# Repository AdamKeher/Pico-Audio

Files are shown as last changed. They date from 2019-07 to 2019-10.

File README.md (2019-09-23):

# picoAUDIO
The audio solution dedicated to the TinyPICO.

Arduino Support Library: https://github.com/AdamKeher/Pico-Audio-Arduino

3d printable base: https://github.com/AdamKeher/Pico-Audio/tree/master/base
## About
The picoAUDIO is a fully featured audio solution specially made for the TinyPICO ESP32 development board, featuring an I2S Stereo DAC, I2S Mono MEMS Microphone, builtin 3.7W Stereo Amplifier, dedicated Headphone Amplifier, I2C GPIO Extender and built-in MicroSD card reader.

We utilise a low power NXP UDA1334A IC featuring a clear digital 16/20/24 bit, 44.1kHz, stereo audio DAC. Accompanying the DAC is a Knowles SPH0645 I2S digital mono microphone. This miniature low power MEMS microphone provides a low noise, 24 bit, 44.1kHz stream. Complimenting the DAC is the powerful Maxim MAX98306 3.7W stereo class D amplifier with stero speaker terminals and a Texas Instrumets TPA6132A2 stereo headphone amplifier with 3.5mm audio jack.

A simple mounting socket hosts the TinyPICO development board and connects all of these great features together in a seamless and easy to utilise footprint measuring a tiny 33 mm x 57 mm (1.29in x 2.24in). To provide maximum connectivity the board features a built-in MicroSD card reader and GPIO extender to hookup 8 inputs and outputs for all of your button and LED needs.
## PCB Layout
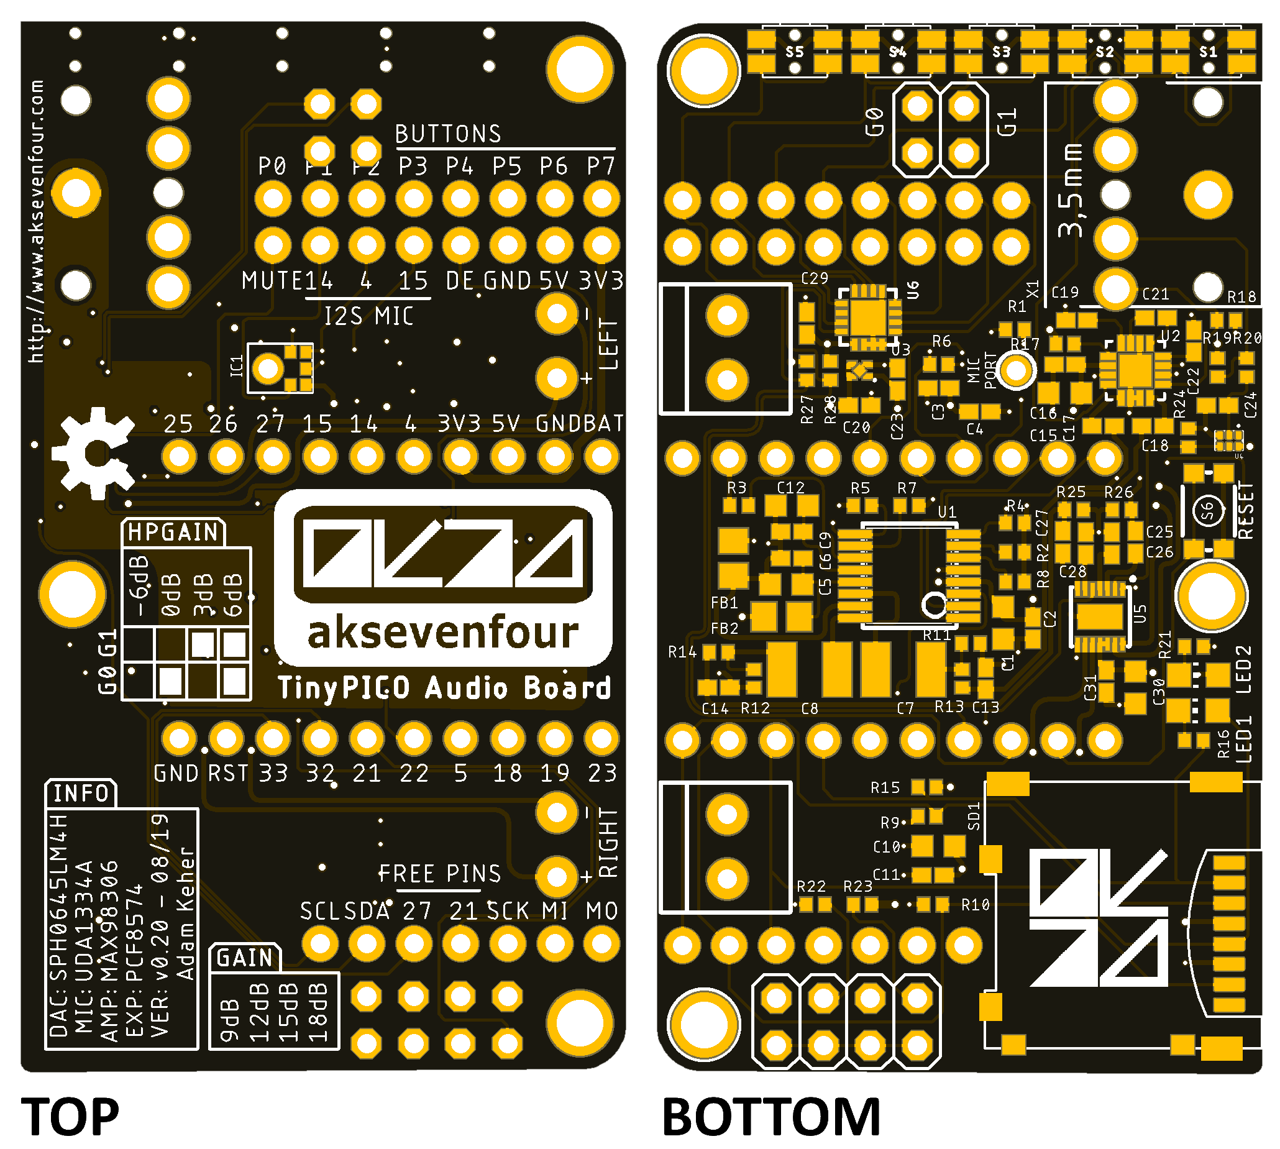
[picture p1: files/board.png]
XCopy Board Image

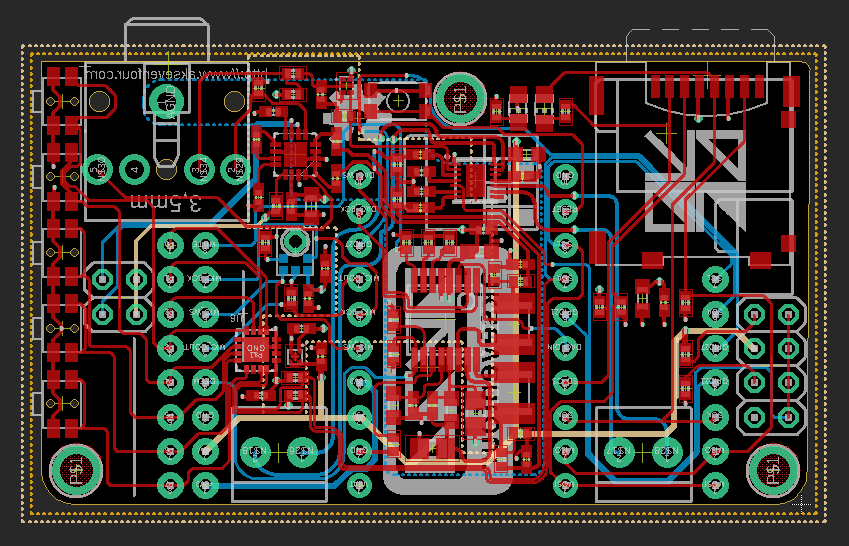
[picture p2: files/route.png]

## Features
The software and hardware used in this project have been made possible by the principle of open hardware and software. Many of the samples have been collected together from a variety of authors and modified to work out of the box with the picoAUDIO for instructional purposes. Please consult each sample project for relevant license and credit.
## Features
* TinyPICO Compatible
  * Simply plug your TinyPICO board into the picoAUDIO and your ready to go
* Audio Out
  * Dedicated Texas Instruments headphone amplifier for distortion free audio.
  * 3.5mm headphone jack. Plug in headphones or line out to an external device.
  * Stereo screw clamp audio terminals. The speaker terminals automatically mute when the 3.5mm jack is used.
* Built-in MicroSD Card
  * Quality Molex mechanism
  * Simple SPI interface
  * Activity LED light
  * Push-Push socket with overhanging edge mounted card for easy insertion
* UDA1334A Stereo DAC
  * Low power audio DAC
  * Integrated digital filter and switchable digital de-emphasis for 44.1 kHz frequency
  * Supports samples from 16 to 100 kHz
  * Simple I2S interface
  * 16/20/24 bit audio
  * High linearity, wide dynamic range and low distortion
* MAX98306 Stereo Amplifier
  * Low power efficient operation
  * 3.7W @ 3Ohm, 10% THD / 1.7W at 8Ohm, 10% THD
  * Spread Spectrum Modulation
  * Five selectable gain levels
  * Excellent click and pop suppression
* TPA6132A2 Headphone Amplifier
  * 25mW Headphone Amplifier for 16/32Ω Headphones with 3.5mm Audio Jack  
  * Unlike most audioboards, the picoAUDIO features a dedicated headphone amplifer
  * Doesn't use caps to drive headphone audio, reducing unwanted noise and distortion
  * Click and pop supression
  * Low power amplifier @ 2.1mA typical supply current
  * Four selectable gain levels
* SPH0645LM4H MEMS Microphone
  * Low power design
  * Simple I2S interface
  * Flat frequency response
  * 24 bit, 44.1kHz audio
  * High SNR of 65dB(A)
  * RF shielded
  * Omnidirectional
* PCF8574 GPIO Extender
  * Low standby current
  * I2C programmable
  * Latched outputs with enough current to drive LEDs
  * 8 Input and Output ports wired to a header with 3 outputs also pre wired to onboard buttons.
## Sample Projects Modified for picoAUDIO
* Stream net radio stations with MP3 support
  * I2C 2x16 character LCD and ILI93411 320x240 TFT display samples provided
* Play audio from SD card with MP3 support
* Record audio to SD card
* Realtime full duplex audio. Vocoder example receives from mic and playback from DAC.

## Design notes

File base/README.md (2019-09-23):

# picoAUDIO
A 3d printable base for the picoAUDIO kindly modelled and provided by Unexpected Maker.

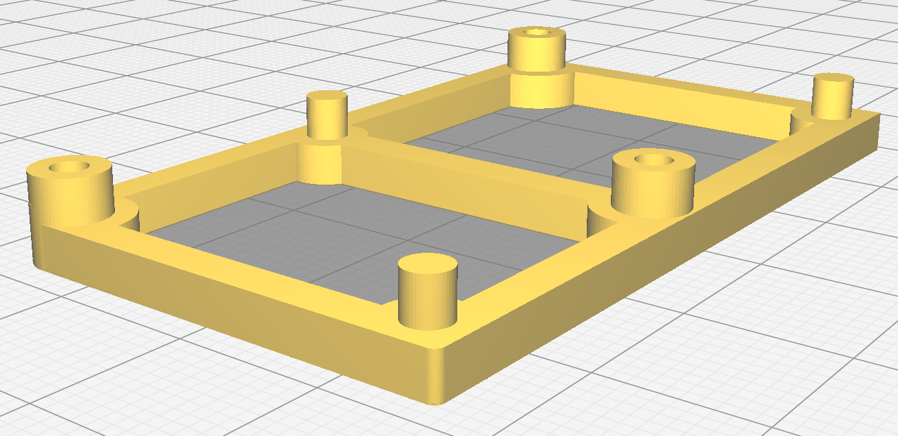
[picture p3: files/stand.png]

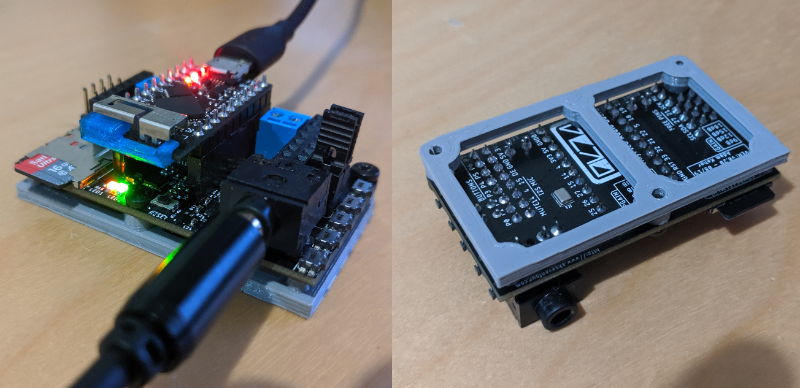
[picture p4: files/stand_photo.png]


https://unexpectedmaker.com/

## Features:
* Raises the picoAUDIO board off the benchtop giving clearance to the pins on the underside of the board.
* Built in standoffs and a flat bottom provide more contact points to the board, increasing stability.
* The bottom of the stand has cut outs to allow the underside pin markings to be visible.
* Does not increase the boards footprint.

## Note
This base requires 2.5mm / M2.5 screws to fix the picoAUDIO to the mounting posts on the base. It is suggested that nylon screws be used to minimise the chance of shorting nearby buttons. If metal screws are used, ensure the head size is small enough to avoid contact with the buttons.

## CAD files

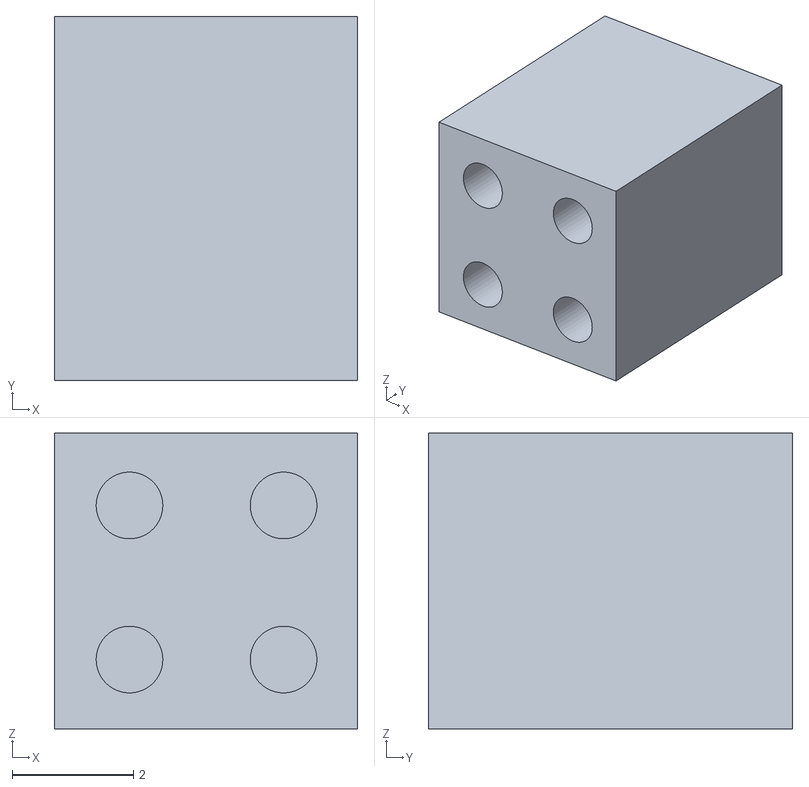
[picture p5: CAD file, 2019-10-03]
base/Headphone Pin Shroud.stl
5.00 x 6.00 x 4.88

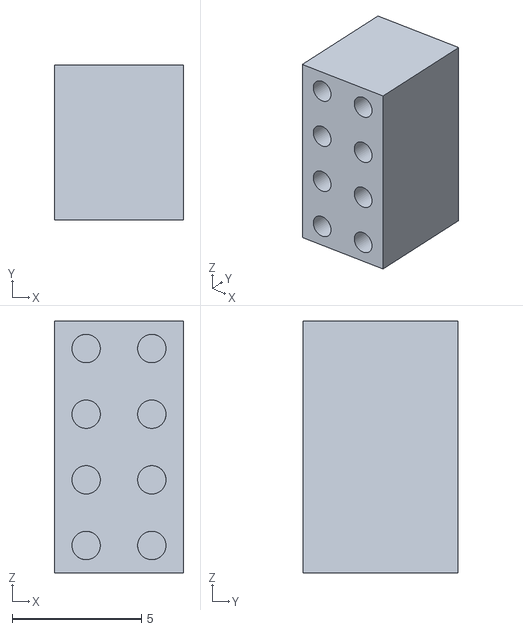
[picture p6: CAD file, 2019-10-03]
base/Speaker Pin Shroud.stl
5.00 x 6.00 x 9.75

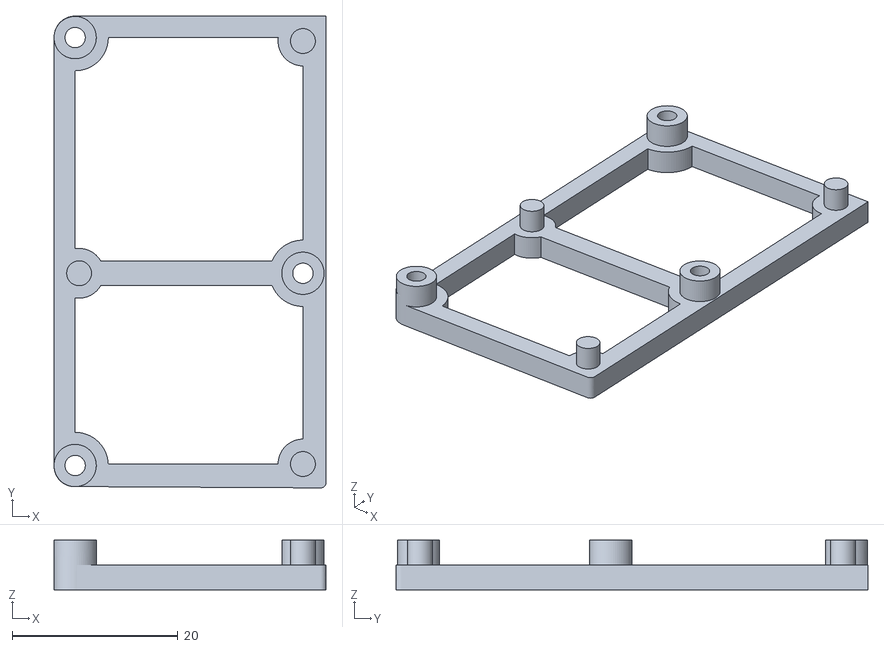
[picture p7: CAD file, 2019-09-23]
base/picoAUDIO base.stl
32.8 x 56.9 x 6.00

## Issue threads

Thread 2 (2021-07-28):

Info silk screen

brad-colbert, 2021-07-28:
I was just looking at the image of the Info section on the silk screen and I think the DAC: and MIC: are swapped.  This is the image on the README.md and may be fixed in the gerber.  Just a "heads up".

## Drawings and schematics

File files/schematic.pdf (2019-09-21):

# GND +3V³#2 100K

# U5 C²⁵ C²⁷

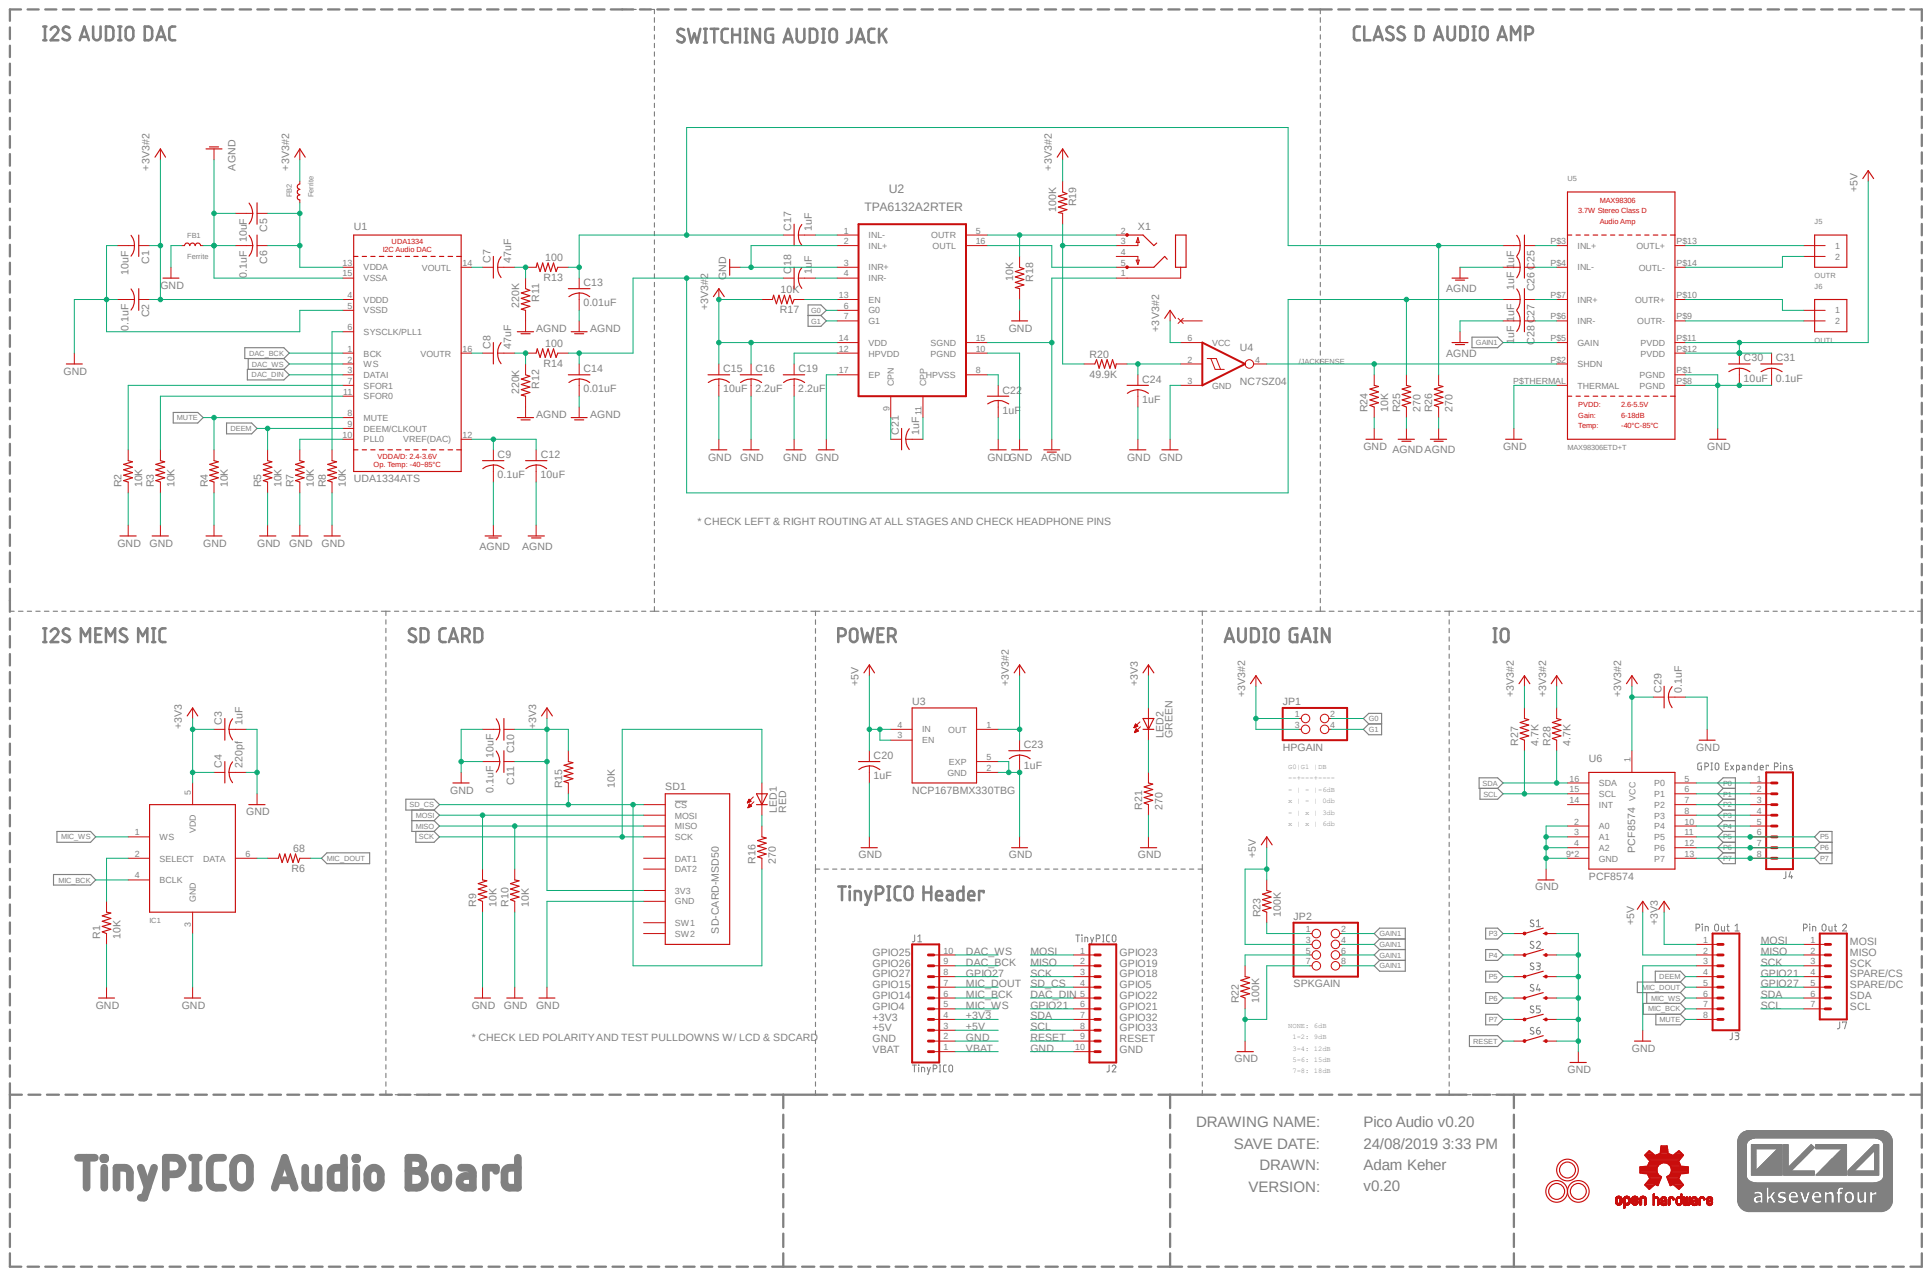
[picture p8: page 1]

* CHECK LEFT & RIGHT ROUTING AT ALL STAGES AND CHECK HEADPHONE PINS

DRAWING NAME:
SAVE DATE: DRAWN: VERSION:

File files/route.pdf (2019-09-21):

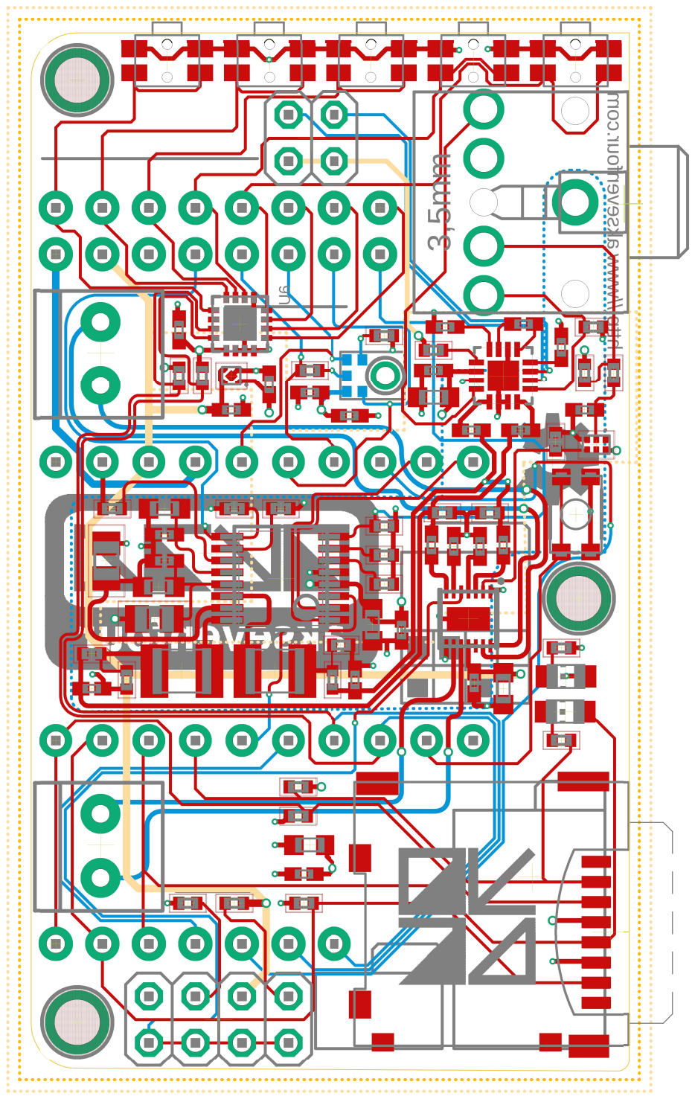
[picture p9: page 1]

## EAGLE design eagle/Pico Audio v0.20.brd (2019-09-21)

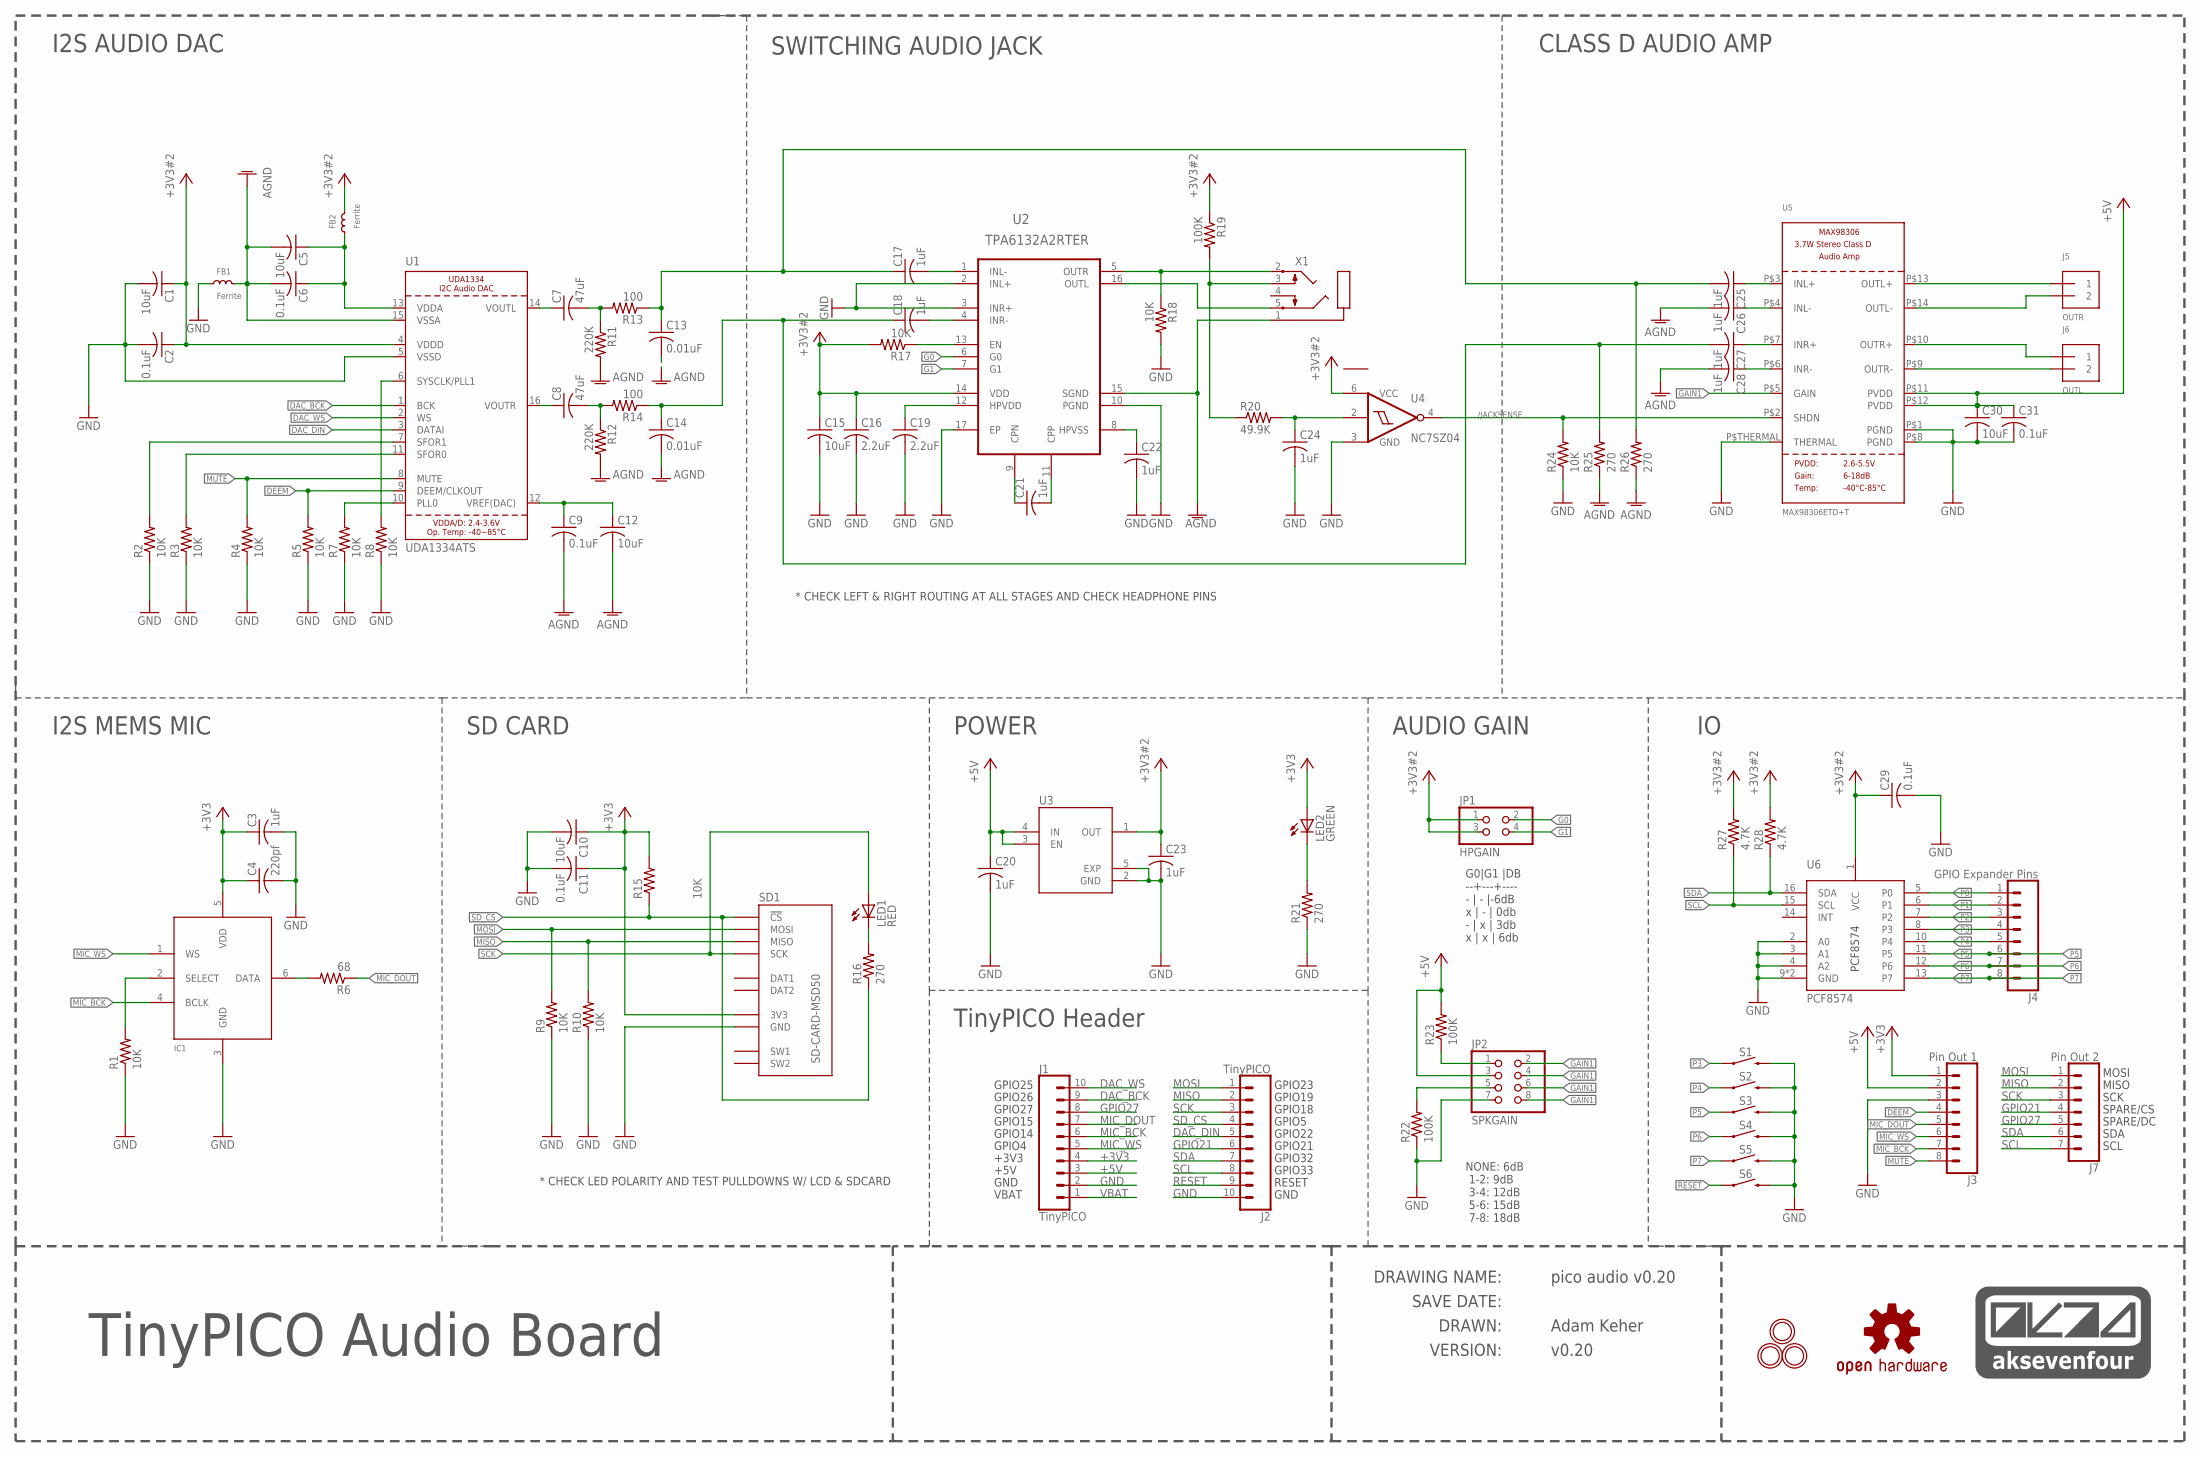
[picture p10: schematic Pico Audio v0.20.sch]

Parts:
AK74LOGO1: AK74_LOGOAK74_LOGO_SMALL; AK74_LOGO_MEDIUM
C1, C5, C10, C12, C15, C30: 10uF; C0603K
C2, C6, C9, C11, C29, C31: 0.1uF; C0402K
C3, C17, C18, C20, C21, C22, C23, C24, C25, C26, C27, C28: 1uF; C0402K
C4: 220pf; C0402K
C7, C8: 47uF; C1210K
C13, C14: 0.01uF; C0402K
C16, C19: 2.2uF; C0402K
FB1, FB2: Ferrite; R0805
IC1: MIC_I2S_SPH0645; SPH0645LM4H
J1, J2: TinyPICO; 1X10_NO_SILK
J3: Pin Out 1; 1X08_NO_SILK
J4: GPIO Expander Pins; 1X08_NO_SILK
J5: OUTR; TERMBLOCK_1X2-3.5MM
J6: OUTL; TERMBLOCK_1X2-3.5MM
J7: Pin Out 2; 1X07_NO_SILK
JP1: HPGAIN; 2X02
JP2: SPKGAIN; 2X04
LED1: RED; CHIP-LED0805
LED2: GREEN; CHIP-LED0805
LOGO1: OSHW-LOGOM; OSHW-LOGO-M
MH1, MH2, MH3: MOUNTINGHOLE2.5; MOUNTINGHOLE_2.5_PLATED
R1, R2, R3, R4, R5, R7, R8, R9, R10, R15, R17, R18, R24: 10K; R0402
R6: 68; R0402
R11, R12: 220K; R0402
R13, R14: 100; R0402
R16, R21, R25, R26: 270; R0402
R19, R22, R23: 100K; R0402
R20: 49.9K; R0402
R27, R28: 4.7K; R0402
S1, S2, S3, S4, S5: SKSCLDE010
S6: MOMENTARY-SWITCH-SPST-SMD-4.6X2.8MM; TACTILE_SWITCH_SMD_4.6X2.8MM
SD1: SD-CARD-MSD50; SD_5031821853
U1: UDA1334ATS; SSOP16_4.4MM
U2: TPA6132A2RTER; QFN50P300X300X80-16N
U3: NCP170AMX300TCG; VREG_NCP170AMX300TCG
U4: NC7SZ04; MICROPAK-6
U5: MAX98306ETD+T; TDFN14_3X3MM
U6: PCF8574; QFN-16-3MM
X1: STEREOJACKSTX3120-5B; STX3100

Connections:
+3V3: C3.1, C4.1, C10.1, C11.1, IC1.5 (VDD), J1.4, J3.1, LED2.A, R15.2, SD1.VCC (3V3)
+3V3#2: C1.1, C2.1, C15.1, C16.1, C23.1, C29.1, FB2.2, JP1.1, JP1.3, R17.2, R19.1, R27.2, R28.2, U1.4 (VDDD), U2.14 (VDD), U3.1 (OUT), U4.6 (VCC), U6.1 (VCC)
+5V: C20.1, C30.1, C31.1, J1.3, J3.2, JP2.3, R23.2, U3.3 (EN), U3.4 (IN), U5.P$11 (PVDD), U5.P$12 (PVDD)
/JACKSENSE: R24.2, U4.4 (Y), U5.P$2 (SHDN)
AGND: C5.2, C6.2, C9.2, C12.2, C13.2, C14.2, C26.2, C28.2, FB1.2, R11.2, R12.2, R25.1, R26.1, U1.15 (VSSA), U2.15 (SGND), X1.1
DAC_BCK: J1.9, U1.1 (BCK)
DAC_DIN: J2.5, U1.3 (DATAI)
DAC_WS: J1.10, U1.2 (WS)
DEEM: J3.4, R5.2, U1.9 (DEEM/CLKOUT)
G0: JP1.2, U2.6 (G0)
G1: JP1.4, U2.7 (G1)
GAIN1: JP2.2, JP2.4, JP2.6, JP2.8, U5.P$5 (GAIN)
GND: C1.2, C2.2, C3.2, C4.2, C10.2, C11.2, C15.2, C16.2, C19.2, C20.2, C22.2, C23.2, C24.2, C29.2, C30.2, C31.2, FB1.1, IC1.3 (GND), J1.2, J2.10, J3.3, JP2.7, R1.1, R2.1, R3.1, R4.1, R5.1, R7.1, R8.1, R9.1, R10.1, R18.2, R21.1, R22.1, R24.1, S1.3 (2), S1.4 (2), S2.3 (2), S2.4 (2), S3.3 (2), S3.4 (2), S4.3 (2), S4.4 (2), S5.3 (2), S5.4 (2), S6.3 (2), S6.4 (2), SD1.GND, U1.5 (VSSD), U2.2 (INL+), U2.3 (INR+), U2.10 (PGND), U2.17 (EP), U3.2 (GND), U3.5 (EXP), U4.3 (GND), U5.P$1 (PGND), U5.P$8 (PGND), U5.P$THERMAL (THERMAL), U6.2 (A0), U6.3 (A1), U6.4 (A2), U6.9 (GND), U6.P$1 (GND)
GPIO21: J2.6, J7.4
GPIO27: J1.8, J7.5
JACKSENSE: C24.1, R20.2, U4.2 (A)
MIC_BCK: IC1.4 (BCLK), J1.6, J3.7
MIC_DOUT: J1.7, J3.5, R6.1
MIC_WS: IC1.1 (WS), J1.5, J3.6
MISO: J2.2, J7.2, R10.2, SD1.MISO
MOSI: J2.1, J7.1, R9.2, SD1.MOSI
MUTE: J3.8, R4.2, U1.8 (MUTE)
unnamed: C5.1, C6.1, FB2.1, U1.13 (VDDA)
unnamed: C25.1, U5.P$3 (INL+)
unnamed: R2.2, U1.7 (SFOR1)
unnamed: C27.1, U5.P$7 (INR+)
unnamed: R3.2, U1.11 (SFOR0)
unnamed: C26.1, U5.P$4 (INL-)
unnamed: C28.1, U5.P$6 (INR-)
unnamed: LED2.C, R21.2
unnamed: C17.2, U2.1 (INL-)
unnamed: R7.2, U1.10 (PLL0)
unnamed: R8.2, U1.6 (SYSCLK/PLL1)
unnamed: C18.2, U2.4 (INR-)
unnamed: R17.1, U2.13 (EN)
unnamed: C9.1, C12.1, U1.12 (VREF(DAC))
unnamed: C7.1, U1.14 (VOUTL)
unnamed: C8.2, R12.1, R14.2
unnamed: J6.2, U5.P$9 (OUTR-)
unnamed: J5.2, U5.P$14 (OUTL-)
unnamed: C7.2, R11.1, R13.2
unnamed: IC1.2 (SELECT), R1.2
unnamed: C8.1, U1.16 (VOUTR)
unnamed: IC1.6 (DATA), R6.2
unnamed: C19.1, U2.12 (HPVDD)
unnamed: JP2.1, R23.1
unnamed: JP2.5, R22.2
unnamed: J5.1, U5.P$13 (OUTL+)
unnamed: LED1.C, R16.2
unnamed: J6.1, U5.P$10 (OUTR+)
unnamed: R18.1, U2.5 (OUTR), X1.2
unnamed: U2.16 (OUTL), X1.5
unnamed: C21.2, U2.11 (CPP)
unnamed: C21.1, U2.9 (CPN)
unnamed: C22.1, U2.8 (HPVSS)
unnamed: R19.2, R20.1, X1.3
P0: J4.1, U6.5 (P0)
P1: J4.2, U6.6 (P1)
P2: J4.3, U6.7 (P2)
P3: J4.4, S1.1, S1.2 (1), U6.8 (P3)
P4: J4.5, S2.1, S2.2 (1), U6.10 (P4)
P5: J4.6, S3.1, S3.2 (1), U6.11 (P5)
P6: J4.7, S4.1, S4.2 (1), U6.12 (P6)
P7: J4.8, S5.1, S5.2 (1), U6.13 (P7)
RESET: J2.9, S6.1, S6.2 (1)
SCK: J2.3, J7.3, LED1.A, SD1.SCK
SCL: J2.8, J7.7, R27.1, U6.15 (SCL)
SDA: J2.7, J7.6, R28.1, U6.16 (SDA)
SD_CS: J2.4, R15.1, R16.1, SD1.CS (!CS)
VBAT: J1.1
VOUTL: C13.1, C17.1, C25.2, R13.1, R26.2
VOUTR: C14.1, C18.1, C27.2, R14.1, R25.2

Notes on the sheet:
I2S MEMS MIC
CLASS D AUDIO AMP
I2S AUDIO DAC
SD CARD
AUDIO GAIN
SAVE DATE:
DRAWN:
VERSION:
DRAWING NAME:
NONE: 6dB 1-2: 9dB 3-4: 12dB 5-6: 15dB 7-8: 18dB
SWITCHING AUDIO JACK
SPARE/CS
MOSI
MISO
SCK
SPARE/DC
POWER
SDA
SCL
TinyPICO Header
GPIO25
GPIO26
GPIO27
GPIO15
GPIO14
GPIO4
+3V3
+5V
GND
VBAT
GPIO23
GPIO19
GPIO18
GPIO5
GPIO22
GPIO21
GPIO32
GPIO33
RESET
G0|G1 |DB --+---+---- - | - |-6dB x | - | 0db - | x | 3db x | x | 6db

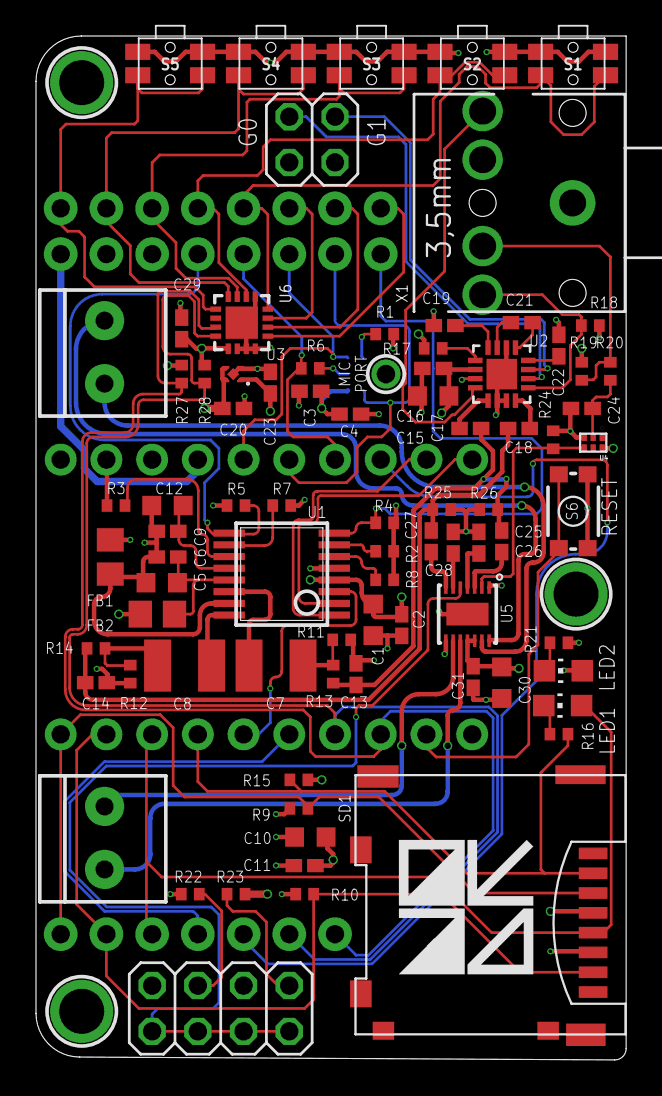
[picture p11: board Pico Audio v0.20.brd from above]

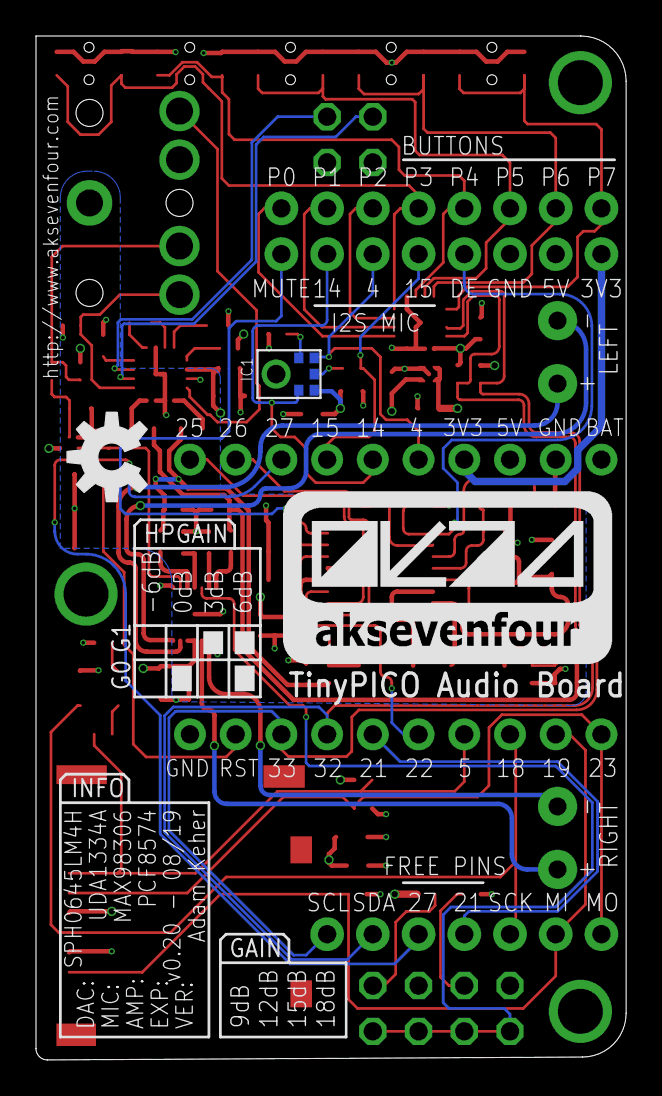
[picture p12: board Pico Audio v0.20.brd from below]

Board: 4 copper layers, 32.8 x 56.9 mm, 93 parts (3 on the bottom side), 71 nets.

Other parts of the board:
U$1: AK74_LOGO_MEDIUM_TEXTONLY_SQUARE

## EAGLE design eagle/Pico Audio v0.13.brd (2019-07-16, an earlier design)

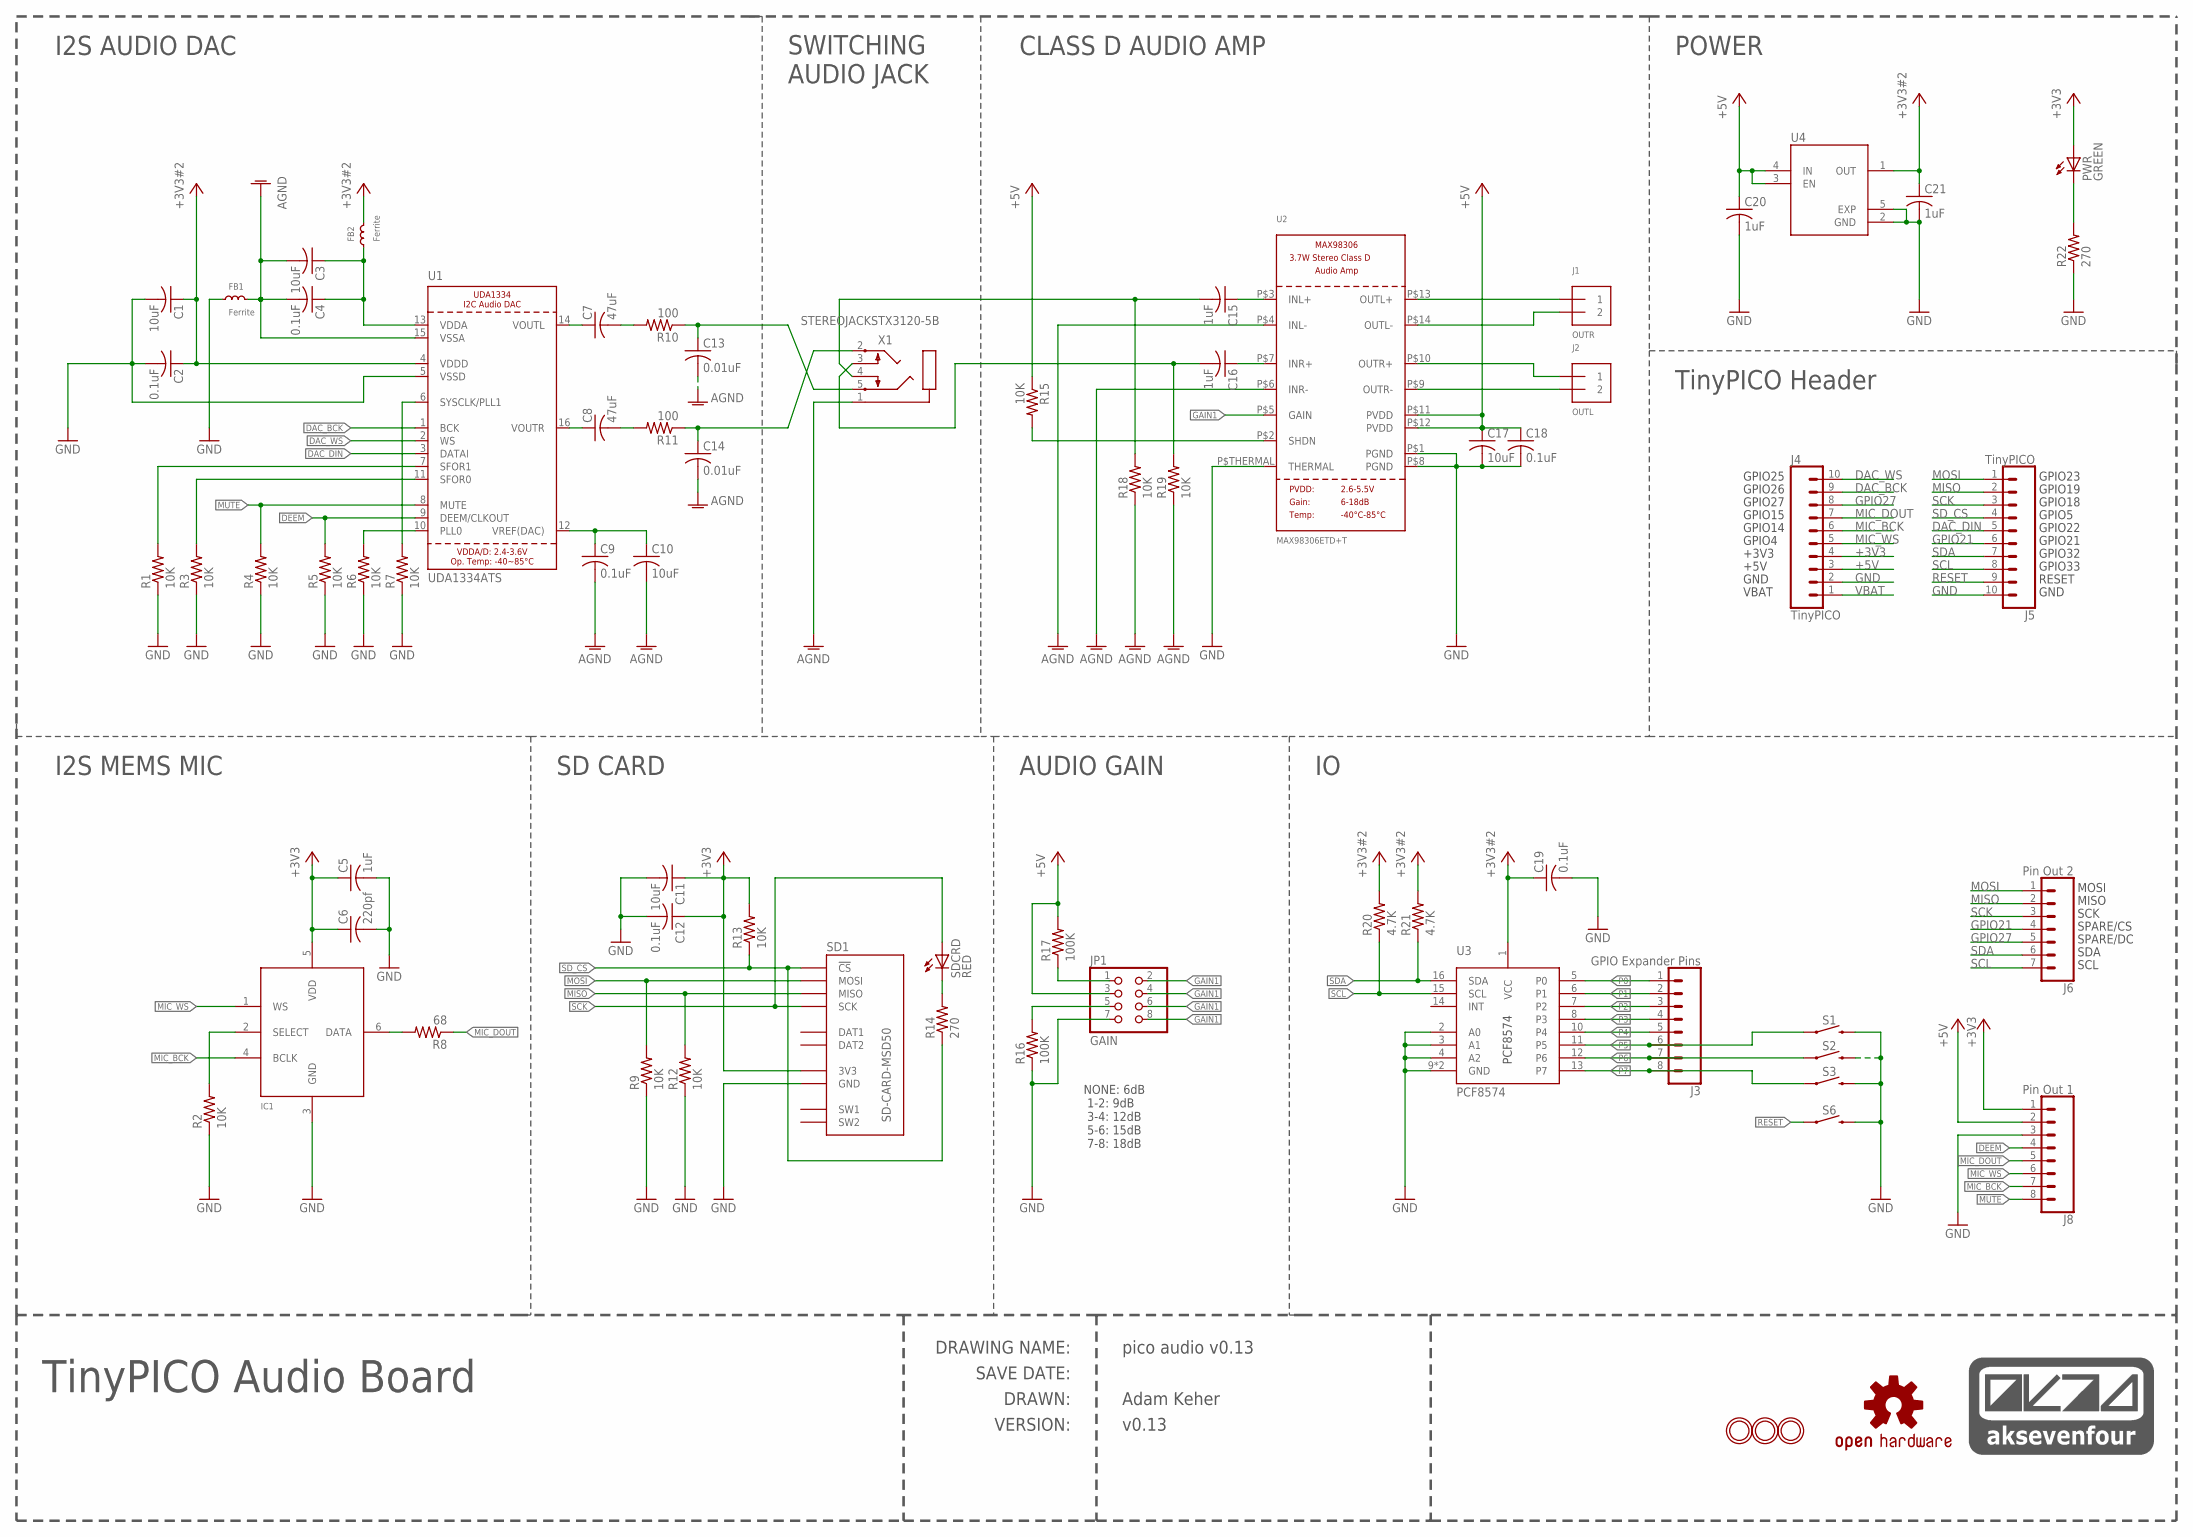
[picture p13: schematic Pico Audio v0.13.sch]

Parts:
AK74LOGO2: AK74_LOGOAK74_LOGO_SMALL; AK74_LOGO_MEDIUM
C1, C3, C10, C11, C17: 10uF; C0603K
C2, C4, C9, C12, C18, C19: 0.1uF; C0402K
C5, C15, C16, C20, C21: 1uF; C0402K
C6: 220pf; C0402K
C7, C8: 47uF; C1210K
C13, C14: 0.01uF; C0402K
FB1, FB2: Ferrite; R0805
IC1: MIC_I2S_SPH0645; SPH0645LM4H
J1: OUTR; TERMBLOCK_1X2-3.5MM
J2: OUTL; TERMBLOCK_1X2-3.5MM
J3: GPIO Expander Pins; 1X08_NO_SILK
J4, J5: TinyPICO; 1X10_NO_SILK
J6: Pin Out 2; 1X07_NO_SILK
J8: Pin Out 1; 1X08_NO_SILK
JP1: GAIN; 2X04
LOGO1: OSHW-LOGOM; OSHW-LOGO-M
MH1, MH2, MH3: MOUNTINGHOLE2.5; MOUNTINGHOLE_2.5_PLATED
PWR: GREEN; CHIP-LED0805
R1, R2, R3, R4, R5, R6, R7, R9, R12, R13, R15, R18, R19: 10K; R0402
R8: 68; R0402
R10, R11: 100; R0402
R14, R22: 270; R0402
R16, R17: 100K; R0402
R20, R21: 4.7K; R0402
S1, S2, S3, S6: MOMENTARY-SWITCH-SPST-SMD-4.6X2.8MM; TACTILE_SWITCH_SMD_4.6X2.8MM
SD1: SD-CARD-MSD50; SD_5031821853
SDCRD: RED; CHIP-LED0805
U1: UDA1334ATS; SSOP16_4.4MM
U2: MAX98306ETD+T; TDFN14_3X3MM
U3: PCF8574; QFN-16-3MM
U4: NCP170AMX300TCG; VREG_NCP170AMX300TCG
X1: STEREOJACKSTX3120-5B; STX3100

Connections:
+3V3: C5.1, C6.1, C11.1, C12.1, IC1.5 (VDD), J4.4, J8.1, PWR.A, R13.2, SD1.VCC (3V3)
+3V3#2: C1.1, C2.1, C19.1, C21.1, FB2.2, R20.2, R21.2, U1.4 (VDDD), U3.1 (VCC), U4.1 (OUT)
+5V: C17.1, C18.1, C20.1, J4.3, J8.2, JP1.3, R15.1, R17.2, U2.P$11 (PVDD), U2.P$12 (PVDD), U4.3 (EN), U4.4 (IN)
AGND: C3.2, C4.2, C9.2, C10.2, C13.2, C14.2, FB1.2, R18.1, R19.1, U1.15 (VSSA), U2.P$4 (INL-), U2.P$6 (INR-), X1.1
DAC_BCK: J4.9, U1.1 (BCK)
DAC_DIN: J5.5, U1.3 (DATAI)
DAC_WS: J4.10, U1.2 (WS)
DEEM: J8.4, R5.2, U1.9 (DEEM/CLKOUT)
GAIN1: JP1.2, JP1.4, JP1.6, JP1.8, U2.P$5 (GAIN)
GND: C1.2, C2.2, C5.2, C6.2, C11.2, C12.2, C17.2, C18.2, C19.2, C20.2, C21.2, FB1.1, IC1.3 (GND), J4.2, J5.10, J8.3, JP1.7, R1.1, R2.1, R3.1, R4.1, R5.1, R6.1, R7.1, R9.1, R12.1, R16.1, R22.1, S1.3 (2), S1.4 (2), S2.3 (2), S2.4 (2), S3.3 (2), S3.4 (2), S6.3 (2), S6.4 (2), SD1.GND, U1.5 (VSSD), U2.P$1 (PGND), U2.P$8 (PGND), U2.P$THERMAL (THERMAL), U3.2 (A0), U3.3 (A1), U3.4 (A2), U3.9 (GND), U3.P$1 (GND), U4.2 (GND), U4.5 (EXP)
GPIO21: J5.6, J6.4
GPIO27: J4.8, J6.5
MIC_BCK: IC1.4 (BCLK), J4.6, J8.7
MIC_DOUT: J4.7, J8.5, R8.1
MIC_WS: IC1.1 (WS), J4.5, J8.6
MISO: J5.2, J6.2, R12.2, SD1.MISO
MOSI: J5.1, J6.1, R9.2, SD1.MOSI
MUTE: J8.8, R4.2, U1.8 (MUTE)
unnamed: C3.1, C4.1, FB2.1, U1.13 (VDDA)
unnamed: C15.1, U2.P$3 (INL+)
unnamed: R1.2, U1.7 (SFOR1)
unnamed: C16.1, U2.P$7 (INR+)
unnamed: R3.2, U1.11 (SFOR0)
unnamed: PWR.C, R22.2
unnamed: R6.2, U1.10 (PLL0)
unnamed: R7.2, U1.6 (SYSCLK/PLL1)
unnamed: C9.1, C10.1, U1.12 (VREF(DAC))
unnamed: C7.1, U1.14 (VOUTL)
unnamed: C8.2, R11.2
unnamed: J2.2, U2.P$9 (OUTR-)
unnamed: J1.2, U2.P$14 (OUTL-)
unnamed: C7.2, R10.2
unnamed: IC1.2 (SELECT), R2.2
unnamed: C8.1, U1.16 (VOUTR)
unnamed: IC1.6 (DATA), R8.2
unnamed: JP1.1, R17.1
unnamed: JP1.5, R16.2
unnamed: J1.1, U2.P$13 (OUTL+)
unnamed: R14.2, SDCRD.C
unnamed: J2.1, U2.P$10 (OUTR+)
P0: J3.1, U3.5 (P0)
P1: J3.2, U3.6 (P1)
P2: J3.3, U3.7 (P2)
P3: J3.4, U3.8 (P3)
P4: J3.5, U3.10 (P4)
P5: J3.6, S1.1, S1.2 (1), U3.11 (P5)
P6: J3.7, S2.1, S2.2 (1), U3.12 (P6)
P7: J3.8, S3.1, S3.2 (1), U3.13 (P7)
RESET: J5.9, S6.1, S6.2 (1)
SCK: J5.3, J6.3, SD1.SCK, SDCRD.A
SCL: J5.8, J6.7, R20.1, U3.15 (SCL)
SDA: J5.7, J6.6, R21.1, U3.16 (SDA)
SD_CS: J5.4, R13.1, R14.1, SD1.CS (!CS)
SHUTDOWN: R15.2, U2.P$2 (SHDN)
VBAT: J4.1
VINL: C15.2, R18.2, X1.4
VINR: C16.2, R19.2, X1.3
VOUTL: C13.1, R10.1, X1.5
VOUTR: C14.1, R11.1, X1.2

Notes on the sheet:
I2S MEMS MIC
CLASS D AUDIO AMP
I2S AUDIO DAC
SD CARD
AUDIO GAIN
SAVE DATE:
DRAWN:
VERSION:
DRAWING NAME:
NONE: 6dB 1-2: 9dB 3-4: 12dB 5-6: 15dB 7-8: 18dB
SWITCHING AUDIO JACK
SPARE/CS
MOSI
MISO
SCK
SPARE/DC
POWER
SDA
SCL
TinyPICO Header
GPIO25
GPIO26
GPIO27
GPIO15
GPIO14
GPIO4
+3V3
+5V
GND
VBAT
GPIO23
GPIO19
GPIO18
GPIO5
GPIO22
GPIO21
GPIO32
GPIO33
RESET

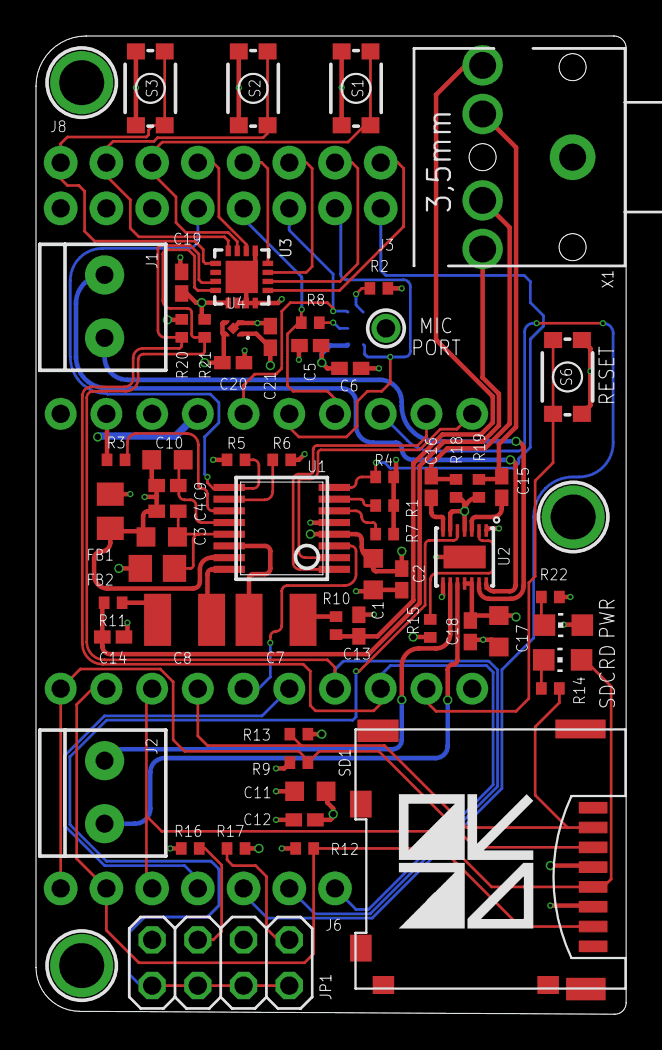
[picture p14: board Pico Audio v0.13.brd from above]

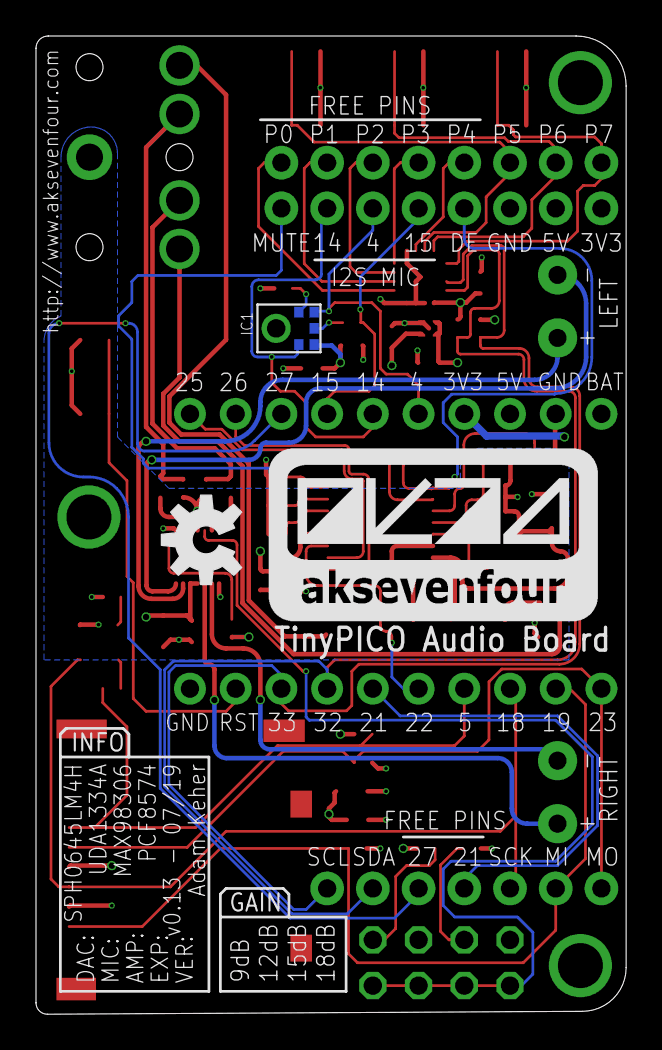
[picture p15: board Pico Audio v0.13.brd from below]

Board: 4 copper layers, 32.8 x 54.3 mm, 72 parts (3 on the bottom side), 58 nets.

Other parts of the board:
U$1: AK74_LOGO_MEDIUM_TEXTONLY_SQUARE

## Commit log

2019-07-16 v0.13 Update
    [Pico Audio v0.10.brd, Pico Audio v0.13.brd, Pico Audio v0.13.sch]
2019-09-19 Initial Arduino library commit
    Framework for picoAUDIO library
2019-09-19 Initial Arduino library commit
2019-09-20 Move Arduino code
2019-09-21 Board Update
    [Pico Audio v0.20.brd, Pico Audio v0.20.sch]
2019-09-21 Revert "Board Update"
    This reverts commit 64f88ad06b88c25f0d87ce8718a64f2d2cec739c.
    [Pico Audio v0.13.brd, Pico Audio v0.13.sch]
2019-09-21 v0.20 Update
    [Pico Audio v0.20.brd, Pico Audio v0.20.sch]
2019-09-23 Added 3d printable base
    [picoAUDIO base.stl]
2019-09-23 3d printable base
    [picoAUDIO base.stl]
2019-10-03 Added Shrouds
    [Headphone Pin Shroud.stl, Speaker Pin Shroud.stl]

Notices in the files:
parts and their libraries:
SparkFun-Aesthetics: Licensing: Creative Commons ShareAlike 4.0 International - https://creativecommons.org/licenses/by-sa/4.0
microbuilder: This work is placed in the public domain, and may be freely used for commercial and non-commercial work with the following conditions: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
